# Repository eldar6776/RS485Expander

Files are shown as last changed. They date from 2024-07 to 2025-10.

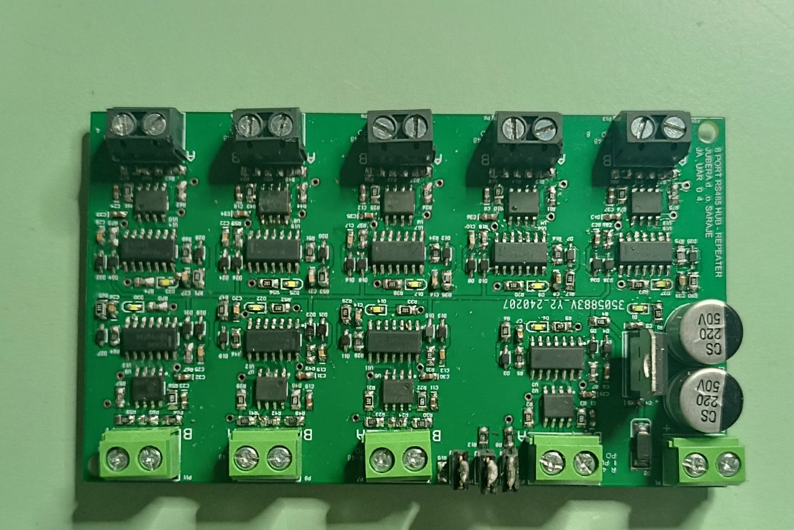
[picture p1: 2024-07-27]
RS458Expander_1.jpg

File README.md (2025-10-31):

# RS485Expander

## Overview

RS485Expander is a non-isolated 9-port RS485 hub designed to expand RS485 networks efficiently and cost-effectively. This device allows you to connect multiple RS485 devices together, making it ideal for industrial automation, building management systems, and other applications where robust multi-drop RS485 communication is required.

## Features

- **9 RS485 Ports**: Connect up to 8 slave devices and 1 master device.
- **Non-Isolated Design**: For cost-sensitive applications where isolation is not required.
- **Compact PCB**: Space-saving design for easy integration into control panels.
- **Robust Communication**: Supports standard RS485 multi-drop protocol.
- **LED Indicators**: Visual feedback for power and communication status (if available in the hardware).

## Typical Applications

- Building automation
- Industrial control systems
- SCADA networks
- Sensor networks
- Data acquisition systems

## Hardware Description

The RS485Expander consists of a PCB with 9 RS485 transceiver circuits. Each port is connected in parallel to support multi-drop communication. The hub is powered via a standard DC jack or terminal block (specify voltage if known). The board is not galvanically isolated; ensure all connected devices share a common ground.

## Schematic & PCB

- Schematic and PCB design files are available in the [`hardware`](./hardware) directory.
- Supported design software:  Altium

## Getting Started

1. **Connect Power**: Apply the required DC voltage (specify rating, e.g., 12V DC).
2. **Connect RS485 Devices**: Use twisted pair cables for the A/B lines and connect common ground.
3. **Termination Resistors**: Add termination resistors at the end devices if required by your network topology.
4. **Test Communication**: Use your RS485 master device to verify communication with all slave ports.

## Pinout

| Port | Description |
|---|---|
| 1-8  | Slave device |
| 9 | Master device |
| GND  | Common ground |

## Safety & Notes

- **Not Isolated**: Do NOT use in applications where isolation is required between ports.
- **Grounding**: Ensure all devices share a common ground to avoid communication errors.
- **Cable Length**: RS485 supports up to 1200 meters total cable length, but keep stubs as short as possible.

## Contributing

Pull requests are welcome! For major changes, please open an issue first to discuss what you would like to change.

## Contact

For questions or support, please contact [repo owner](https://github.com/eldar6776).

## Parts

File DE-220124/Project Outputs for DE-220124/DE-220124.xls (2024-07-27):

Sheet: BOM Report
Bill of Materials |  |  | Bill of Materials For PCB Document [DE-220124.PcbDoc]
Source Data From: |  | DE-220124.PcbDoc
Project: |  | DE-220124.PrjPcb
Variant: |  | None
Creation Date: | 27. 1. 2024. | 11:07:20
Print Date: | 45318 | 45318.46353
Footprint | Comment | LibRef | Designator | Description | Quantity
0603 | 100nF | C0603 | C1, C4, C5, C8, C11, C12, C15, C18, C23, C24, C29, C30, C31, C32, C33, C34, C35, C36, C37, C40 | Ceramic Chip Capacitor - Standard | 20
CAPPR5-10X12.5 | 470uF | EKA00DC347E00 | C2, C3 | Aluminum Electrolytic Capacitor, Radial Style with Long Leads: 470uF, 25V | 2
0603 | 68pF | C0603 | C6, C10, C13, C17, C19, C22, C25, C28 | Ceramic Chip Capacitor - Standard | 8
0603 | 1nF | C0603 | C7, C9, C14, C16, C20, C21, C26, C27, C38, C39 | Ceramic Chip Capacitor - Standard | 10
1.6X0.8X0.8 | HSMZ-C190 | HSMZ-C190 | D1, D6, D9, D14, D17, D22, D25, D30, D33, D37 | High Performance Chip LED, Red | 10
SMB | D Schottky | D Schottky | D2 | Schottky Diode | 1
SOD323 | 1N4148 | BAS321 | D3, D4, D7, D8, D11, D12, D13, D16, D19, D20, D21, D24, D27, D28, D29, D32, D35, D36 | General-purpose Diode | 18
SOD323 | 1N5819 | BAS321 | D5, D10, D15, D18, D23, D26, D31, D34, D38 | General-purpose Diode | 9
TERMINAL BLOK 2 | TERMINAL BLOK 2 | TERMINAL BLOK 2 | P1, P2, P6, P7, P8, P9, P10, P11, P12 | 2 pinski terminal blok | 9
HDR1X2 | PULL UP | Header 2 | P3 | Header, 2-Pin | 1
HDR1X2 | PULL DOWN | Header 2 | P4 | Header, 2-Pin | 1
HDR1X2 | TERMINATE | Header 2 | P5 | Header, 2-Pin | 1
TERMINAL BLOK 2 | RS485 | TERMINAL BLOK 2 | P13 | 2 pinski terminal blok | 1
ERA-0805 | 1K | ERA6Y | R1, R2, R9, R11, R20, R21, R26, R33, R38, R39, R44, R52, R56, R57, R62, R70, R74, R75, R83 | Rectangular Thick Film Chip Resistor, 10 Ohm to 1M Ohm Range, 0.1% and 0.5% Tolerance, 0805 Size, 0.1 W | 19
ERA-0805 | 4K7 | ERA6Y | R3, R10, R22, R25, R40, R43, R58, R61, R76 | Rectangular Thick Film Chip Resistor, 10 Ohm to 1M Ohm Range, 0.1% and 0.5% Tolerance, 0805 Size, 0.1 W | 9
ERA-0805 | 3K9 | ERA6Y | R4 | Rectangular Thick Film Chip Resistor, 10 Ohm to 1M Ohm Range, 0.1% and 0.5% Tolerance, 0805 Size, 0.1 W | 1
ERA-0805 | 27K | ERA6Y | R5, R16, R28, R34, R46, R51, R64, R69, R79, R82 | Rectangular Thick Film Chip Resistor, 10 Ohm to 1M Ohm Range, 0.1% and 0.5% Tolerance, 0805 Size, 0.1 W | 10
ERA-0805 | 120R | ERA6Y | R6, R14, R15, R17, R24, R29, R32, R35, R42, R47, R50, R53, R60, R65, R68, R71, R78, R80 | Rectangular Thick Film Chip Resistor, 10 Ohm to 1M Ohm Range, 0.1% and 0.5% Tolerance, 0805 Size, 0.1 W | 18
ERA-0805 | 10K | ERA6Y | R7, R19, R31, R37, R49, R55, R67, R73 | Rectangular Thick Film Chip Resistor, 10 Ohm to 1M Ohm Range, 0.1% and 0.5% Tolerance, 0805 Size, 0.1 W | 8
ERA-0805 | 680R | ERA6Y | R8, R12, R13, R18, R23, R27, R30, R36, R41, R45, R48, R54, R59, R63, R66, R72, R77, R81 | Rectangular Thick Film Chip Resistor, 10 Ohm to 1M Ohm Range, 0.1% and 0.5% Tolerance, 0805 Size, 0.1 W | 18
TO220V | L78M05CV | L78M05CV | U1 | Positive Voltage Regulator | 1
D008_L | MAX485 | SN75176BD | U2, U4, U5, U6, U7, U8, U9, U10, U18 | Differential Bus Transceiver | 9
751A-03_N | MC74AC00D | MC74AC00D | U3, U11, U12, U13, U14, U15, U16, U17, U19 | Quad 2-Input NAND Gate | 9
 |  |  |  |  | 193
Approved |  | Notes

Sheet: Project Information
Project Full Path | I:\ProjektiOtvoreni\Sjenica\hw\RS485HUB8\DE-220124.PrjPcb
Project Filename | DE-220124.PrjPcb
Variant Name | None
Data-Source Filename | DE-220124.PcbDoc
Data-Source Full Path | I:\ProjektiOtvoreni\Sjenica\hw\RS485HUB8\DE-220124.PcbDoc
Title | Bill of Materials For PCB Document [DE-220124.PcbDoc]
Total Quantity | 193
Report Time | 11:07:20
Report Date | 27. 1. 2024.
Report Date & Tine | 27. 1. 2024. 11:07:20
Output Name | Bill of Materials
Output Type | BOM_PartType
Output Generator Name | BOM
Output Generator Description | Bill of Materials

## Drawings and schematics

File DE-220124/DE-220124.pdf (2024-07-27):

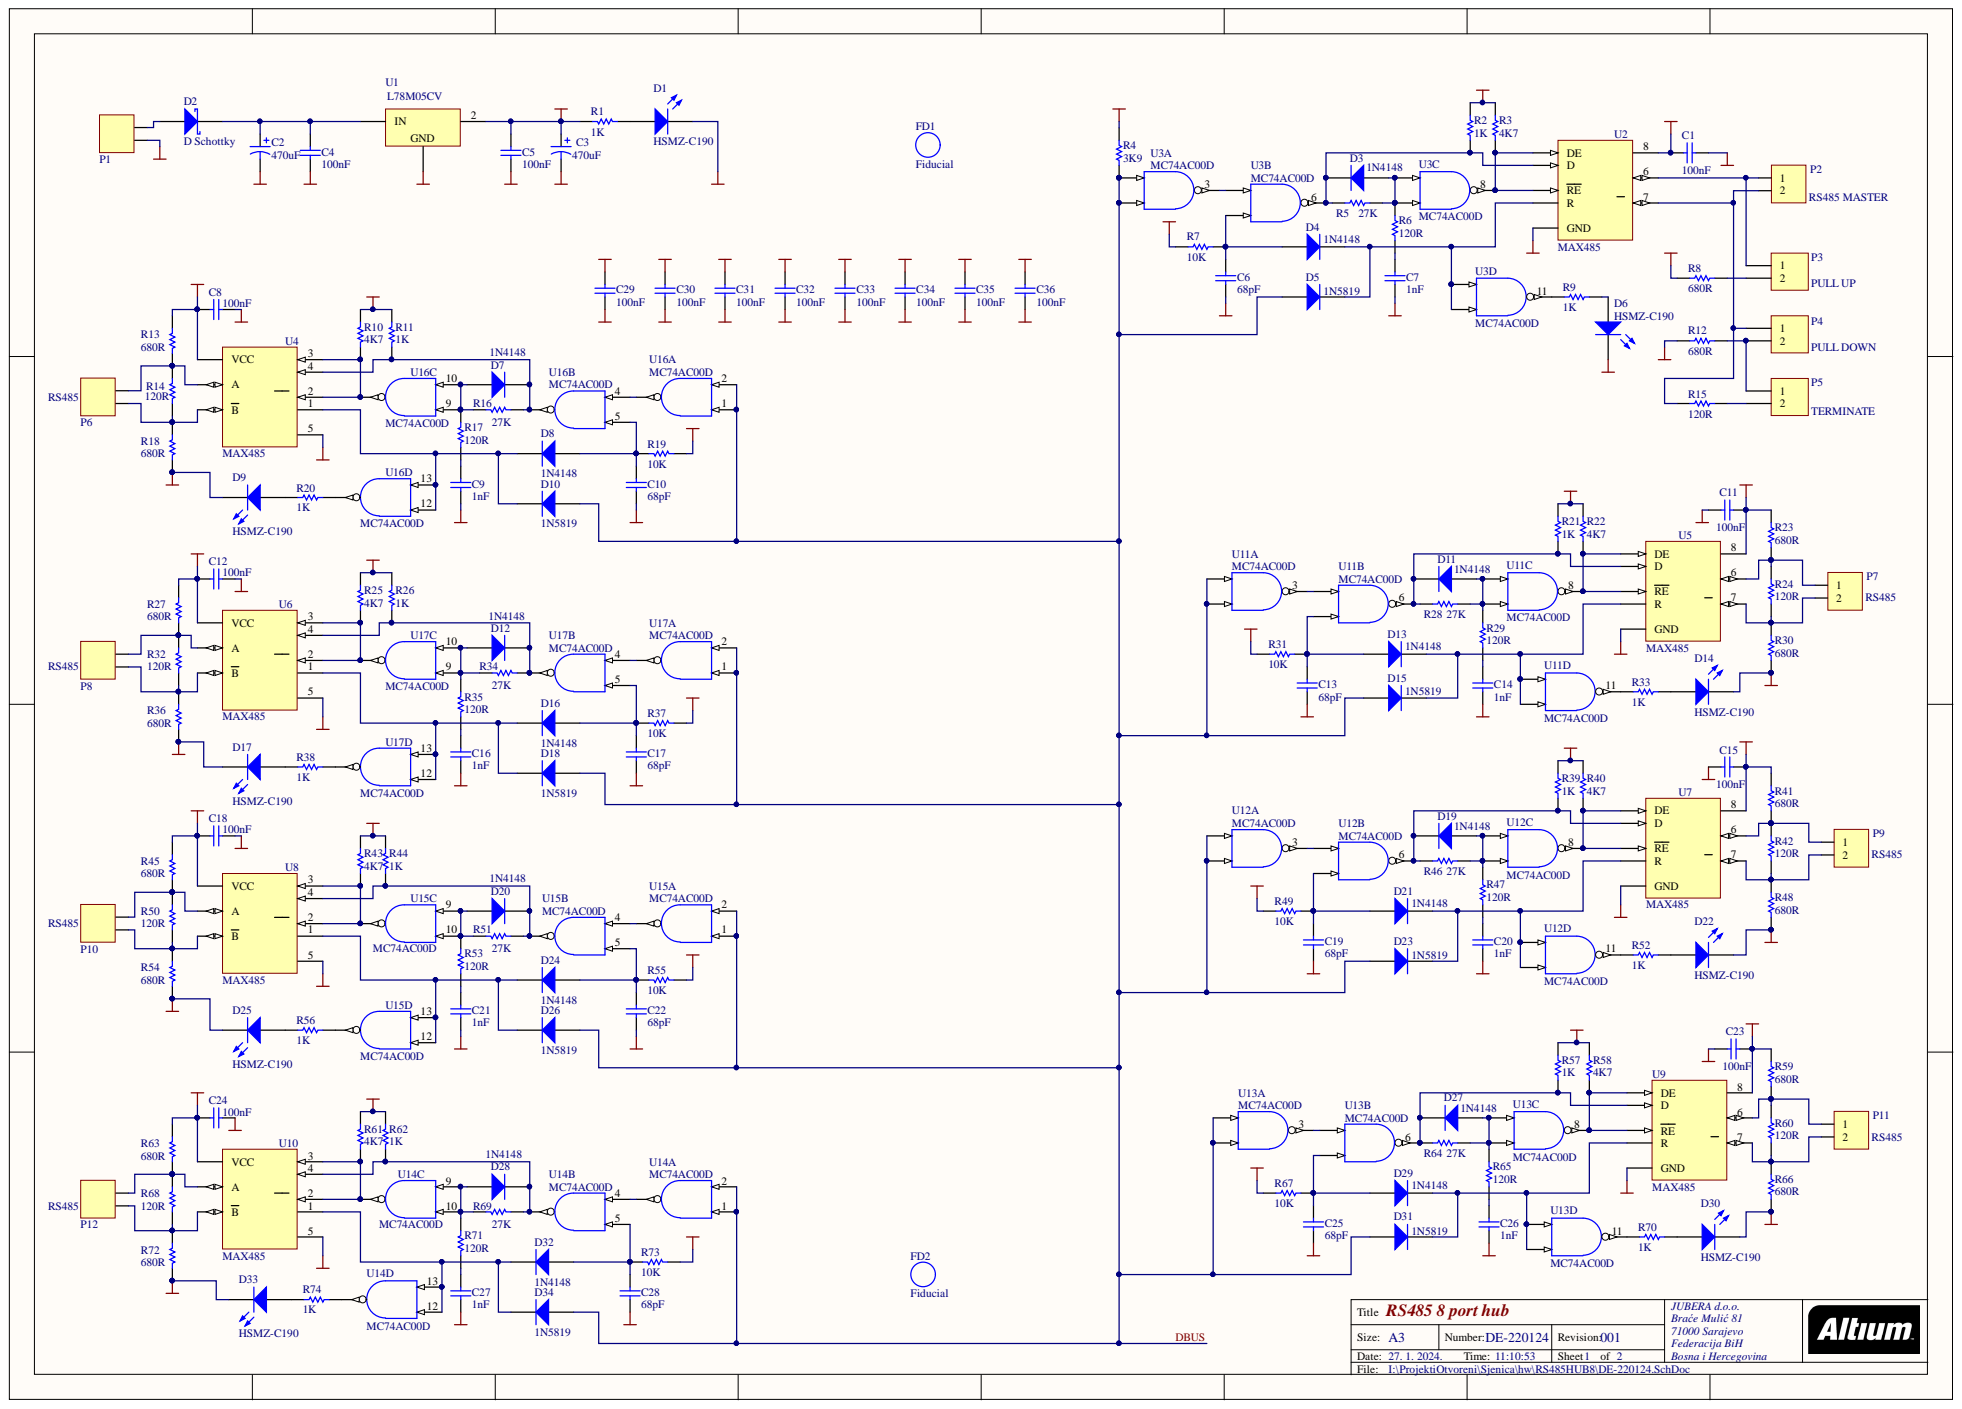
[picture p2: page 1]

Fiducial

RS485 8 port hub Title | JUBERA d.o.o. Braće Mulić 81 71000 Sarajevo Federacija BiH Bosna i Hercegovina

Size: A3 | Number: DE-220124 | Revision: 001
Date: 27. 1. 2024. Time: 11:10:53 | | Sheet 1 of 2

I:\ProjektiOtvoreni\Sjenica\hw\RS485HUB8\DE-220124.SchDoc

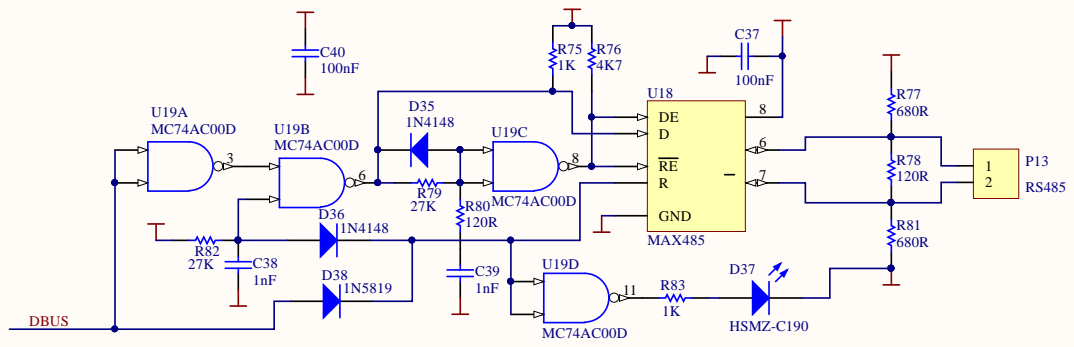
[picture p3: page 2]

RS48 5 8 p ort hub T i t l e | JUB ERA d.o.o . B r a će M u l i ć 8 1 7 1 0 0 0 S a r ajevo Feder acij a B i H B o s n a i Herceg ovi n a

A4 Size: | DE-2 2 0 1 2 4 N umber: | 0 0 1 Rev i s i o n :
Date: 2 7. 1. 2 0 2 4 . T ime: 1 1 : 1 0 : 5 4 | | Sheet 2 o f 2

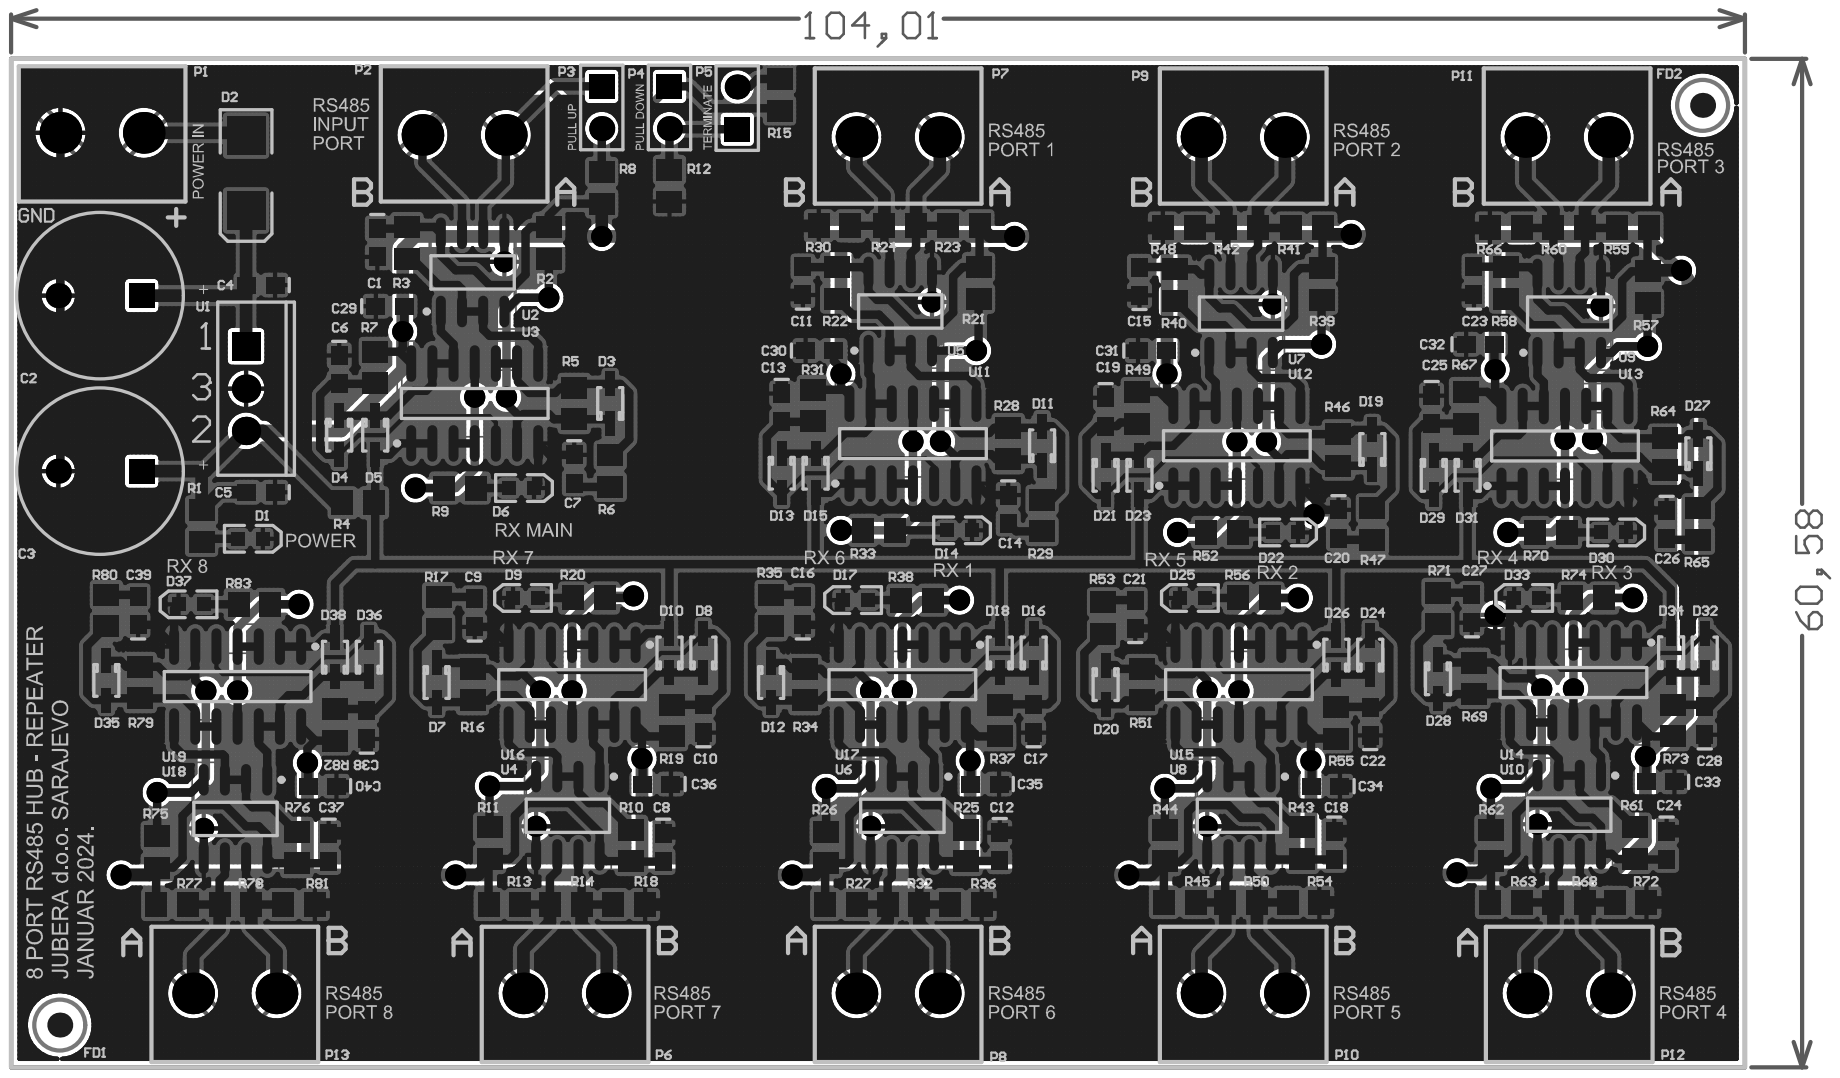
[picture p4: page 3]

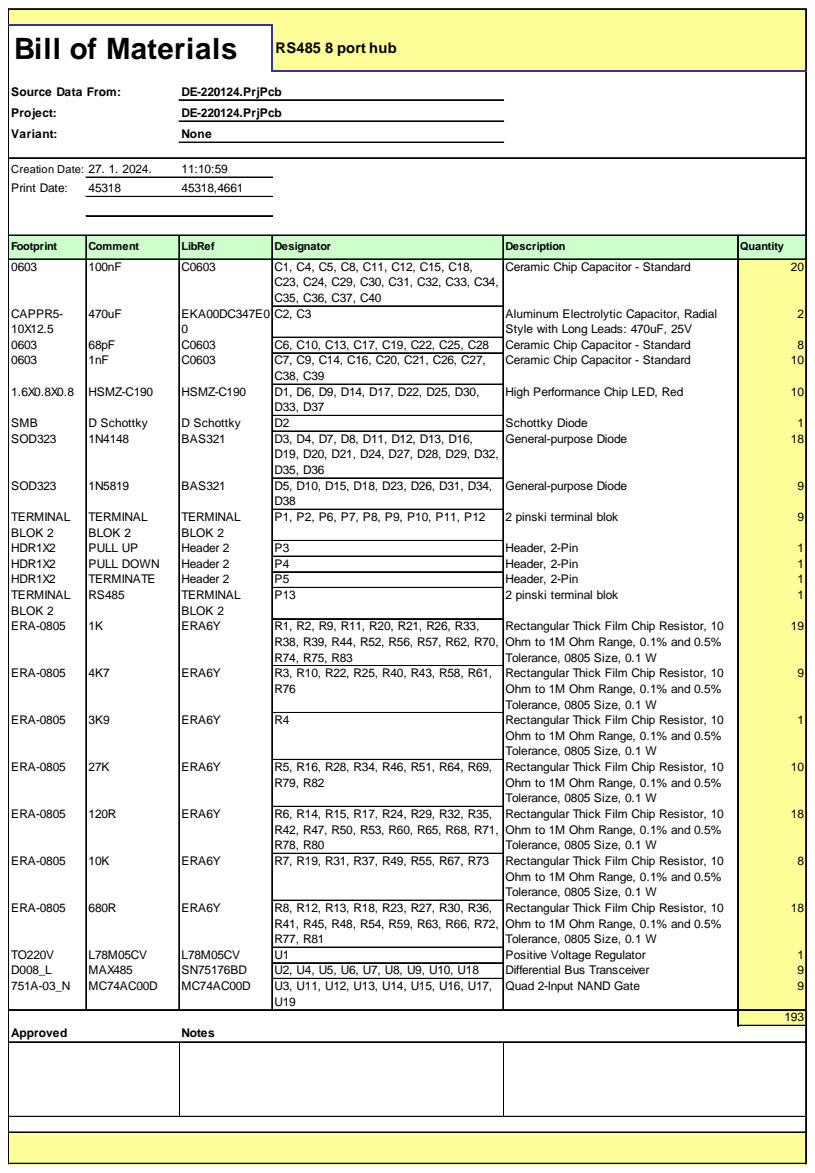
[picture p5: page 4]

Footprint | Comment | LibRef | Designator | Description | Quantity

Style with Long Leads: 470uF, 25V

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
